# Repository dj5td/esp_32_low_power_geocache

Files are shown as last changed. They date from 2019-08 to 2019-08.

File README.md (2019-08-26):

# ESP 32 low power geocache
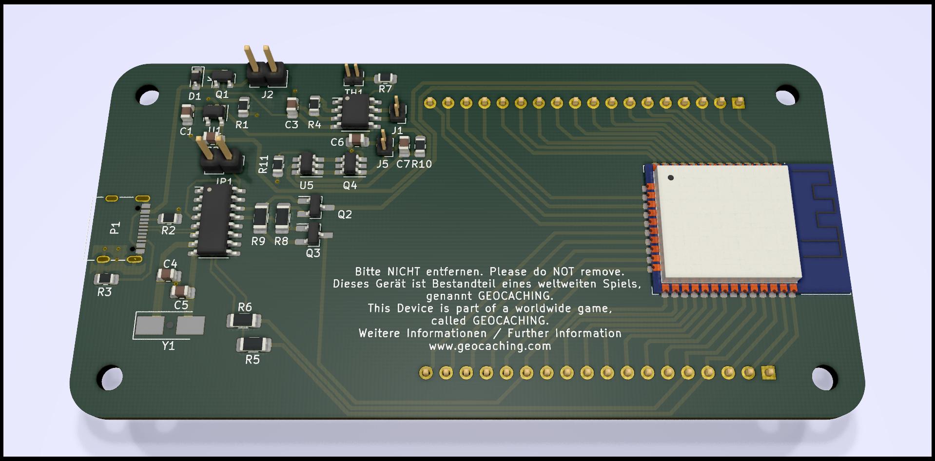
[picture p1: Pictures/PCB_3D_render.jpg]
Smiley face


## Idea and Goals

### Idea

### Goals

## Schematic

## Parts
You can find a bill of materials (BOM) file for LCSC in the repository. Not included are pinheaders, solar panel and the lithium-ion battery.
## Software
Software will be developed once I received and built the first prototype. Hang in there.
## License


This project is licensed under the Creative Commons Attribution-NonCommercial-ShareAlike 4.0 International licence. See the [LICENSE.md](LICENSE.md) file for details.
## Acknowledgments
Special thanks go out to my amateur radio friends who helped me a lot during design of the schematic and PCB:
* Mathias Weyland
* Oliver
* Rune Broberg

You guys show us that amateur radio still is about experimenting with hardware and software, and that it is even more amazing to do so nowadays than ever before. This international community is amazing and I encourage everyone interested in tinkering, creating and engineering to join us.

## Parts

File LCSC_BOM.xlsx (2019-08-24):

LCSC Part Number | Manufacture Part Number | Manufacturer | Package | Description | RoHS | Order Qty. | Min\Mult Order Qty. | Unit Price | Order Price | Product Link
C95209 | ESP32-WROOM-32 | Espressif Systems | Module | WIFI Modules Module RoHS | yes | 3 | 1\1 | 3.197 | 9.591 | https://lcsc.com/product-detail/WIFI-Modules_ESP-WROOM-32_C95209.html
C181158 | S8050 | Guangdong Hottech | SOT-23(SOT-23-3) | Transistors (NPN/PNP) NPN 500mA 25V SOT-23(SOT-23-3) RoHS | yes | 50 | 50\50 | 0.0082 | 0.41 | https://lcsc.com/product-detail/Transistors-NPN-PNP_S8050_C181158.html
C1491 | 1206W4J0123T5E | Uniroyal Elec | 1206 | Chip Resistor - Surface Mount 12KOhms ±5% 1/4W 1206 RoHS | yes | 100 | 100\100 | 0.0018 | 0.18 | https://lcsc.com/product-detail/Chip-Resistor-Surface-Mount_Uniroyal-Elec-1206W4J0123T5E_C1491.html
C118071 | RS-06K471JT | Guangdong Fenghua Advanced Tech | 1206 | Chip Resistor - Surface Mount 470Ohms ±5% 1/4W 1206 RoHS | yes | 100 | 100\100 | 0.0018 | 0.18 | https://lcsc.com/product-detail/Chip-Resistor-Surface-Mount_470R-471-5_C118071.html
C115337 | RS-05K512JT | Guangdong Fenghua Advanced Tech | 0805 | Chip Resistor - Surface Mount 5.1KOhms ±5% 1/8W 0805 RoHS | yes | 100 | 100\100 | 0.0011 | 0.11 | https://lcsc.com/product-detail/Chip-Resistor-Surface-Mount_5-1KR-512-5_C115337.html
C102017 | CR0805J80472G | LIZ Elec | 0805 | Chip Resistor - Surface Mount 4.7KOhms ±5% 1/8W 0805 RoHS | yes | 100 | 100\100 | 0.0011 | 0.11 | https://lcsc.com/product-detail/Chip-Resistor-Surface-Mount_4-7KR-472-5_C102017.html
C1365 | 0805W8J0362T5E | Uniroyal Elec | 0805 | Chip Resistor - Surface Mount 3.6KOhms ±5% 1/8W 0805 RoHS | yes | 100 | 100\100 | 0.0011 | 0.11 | https://lcsc.com/product-detail/Chip-Resistor-Surface-Mount_Uniroyal-Elec-0805W8J0362T5E_C1365.html
C115302 | RS-05K102JT | Guangdong Fenghua Advanced Tech | 0805 | Chip Resistor - Surface Mount 1KOhms ±5% 1/8W 0805 RoHS | yes | 100 | 100\100 | 0.001 | 0.1 | https://lcsc.com/product-detail/Chip-Resistor-Surface-Mount_1KR-102-5_C115302.html
C24658 | 0805CG220J500NT | Guangdong Fenghua Advanced Tech | 0805 | Multilayer Ceramic Capacitors MLCC - SMD/SMT 22pF 50V 0805 RoHS | yes | 50 | 50\50 | 0.0051 | 0.255 | https://lcsc.com/product-detail/Multilayer-Ceramic-Capacitors-MLCC-SMD-SMT_22pF-220-5-50V_C24658.html
C307523 | CL21A106KPFNNNG | Samsung Electro-Mechanics | 0805 | Multilayer Ceramic Capacitors MLCC - SMD/SMT 10uF 10V 0805 RoHS | yes | 50 | 50\50 | 0.0089 | 0.445 | https://lcsc.com/product-detail/Others_Samsung-Electro-Mechanics_CL21A106KPFNNNG_Samsung-Electro-Mechanics-CL21A106KPFNNNG_C307523.html
C96454 | CL21A475KPFNNNE | Samsung Electro-Mechanics | 0805 | Multilayer Ceramic Capacitors MLCC - SMD/SMT 4.7uF 10V 0805 RoHS | yes | 50 | 50\50 | 0.013 | 0.65 | https://lcsc.com/product-detail/Others_Samsung-Electro-Mechanics_CL21A475KPFNNNE_Samsung-Electro-Mechanics-CL21A475KPFNNNE_C96454.html
C112573 | X503212MSB2GI | Yangxing Tech | SMD-5032_2P | SMD Crystal Resonators 12MHz ±10ppm SMD-5032_2P RoHS | yes | 3 | 1\1 | 0.1727 | 0.5181 | https://lcsc.com/product-detail/SMD-Crystal-Resonators_Yangxing-Tech-X503212MSB2GI_C112573.html
C319148 | U262-161N-4BVC11 | XKB Enterprise | SMT | USB Connectors SMT RoHS | yes | 3 | 1\1 | 0.3136 | 0.9408 | https://lcsc.com/product-detail/USB-Connectors_XKB-Enterprise-U262-16XN-4BVC11_C319148.html
C123378 | MF52A103J3950 (A1) | Nanjing Shiheng Elec | Through Hole,P=1.7mm | NTC Thermistors 1/20W 10KOhms ±5% 3950K Through Hole,P=1.7mm RoHS | yes | 20 | 20\20 | 0.0263 | 0.526 | https://lcsc.com/product-detail/NTC-Thermistors_10K-5_C123378.html
C123899 | B5817WS | Shandong Jingdao Microelectronics | SOD-323 | Schottky Barrier Diodes (SBD) SOD-323 RoHS | yes | 20 | 20\20 | 0.0163 | 0.326 | https://lcsc.com/product-detail/Schottky-Barrier-Diodes-SBD_Shandong-Jingdao-Microelectronics-B5817WS_C123899.html
C77937 | LP2301LT1G | Leshan Radio | SOT-23(SOT-23-3) | MOSFET P Trench 20V 2.3A 900mV @ 250uA 100 mΩ @ 2.8A,4.5V SOT-23(SOT-23-3) RoHS | yes | 10 | 10\10 | 0.033 | 0.33 | https://lcsc.com/product-detail/MOSFET_Leshan-Radio-LP2301LT1G_C77937.html
C14267 | CH340G | Jiangsu Qin Heng | SOP-16_150mil | USB 2Mbps 3.3V, 5V SOP-16_150mil RoHS | yes | 3 | 1\1 | 0.4061 | 1.2183 | https://lcsc.com/product-detail/USB_CH340G_C14267.html
C86534 | XC6220B331MR-G | Torex Semicon | SOT-25 | Low Dropout Regulators(LDO) Positive Fixed 655mV @ 1A 6V 3.3V 1A SOT-25 RoHS | yes | 3 | 1\1 | 0.2515 | 0.7545 | https://lcsc.com/product-detail/Low-Dropout-Regulators-LDO_XC6220B331MR-G_C86534.html
C28078 | CN3063 | ShangHai Consonance Elec | SOIC-8_EP_150mil | PMIC - Battery Management SOIC-8_EP_150mil RoHS | yes | 3 | 1\1 | 0.5455 | 1.6365 | https://lcsc.com/product-detail/PMIC-AC-DC-Converters_ShangHai-Consonance-Elec-CN3063_C28078.html

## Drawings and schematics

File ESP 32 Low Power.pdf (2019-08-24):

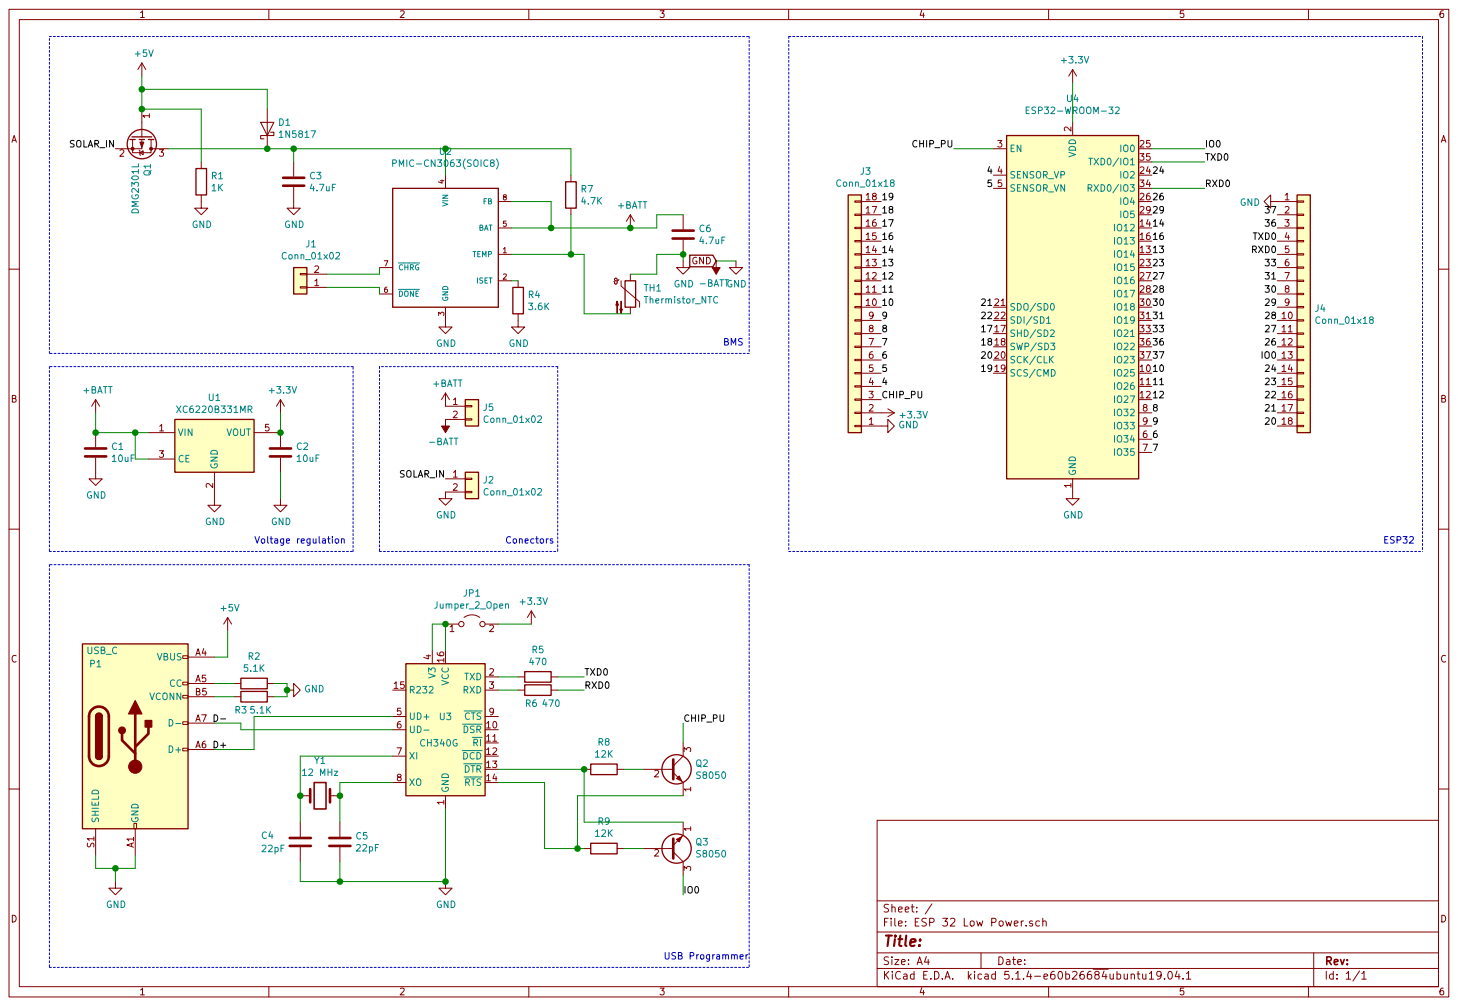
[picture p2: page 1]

4 BAT 5 DONE 6 CHRG 7 FB 8 U2 PMIC-CN3063(SOIC8) D1

2 SCK/CLK 20 SDO/SD0 21 SDI/SD1 22

2 CE 3 VOUT 5 U1 XC6220B331MR GND GND

Id: 1/1 Title: File: ESP 32 Low Power.sch Sheet: / +5V

1 DSR 10 RI 11 DCD 12 DTR 13 RTS 14 R232 15 VCC 16 TXD 2 RXD 3 V3

4 UD+ 5 UD- 6 XI 7 XO 8 CTS 9 U3 CH340G

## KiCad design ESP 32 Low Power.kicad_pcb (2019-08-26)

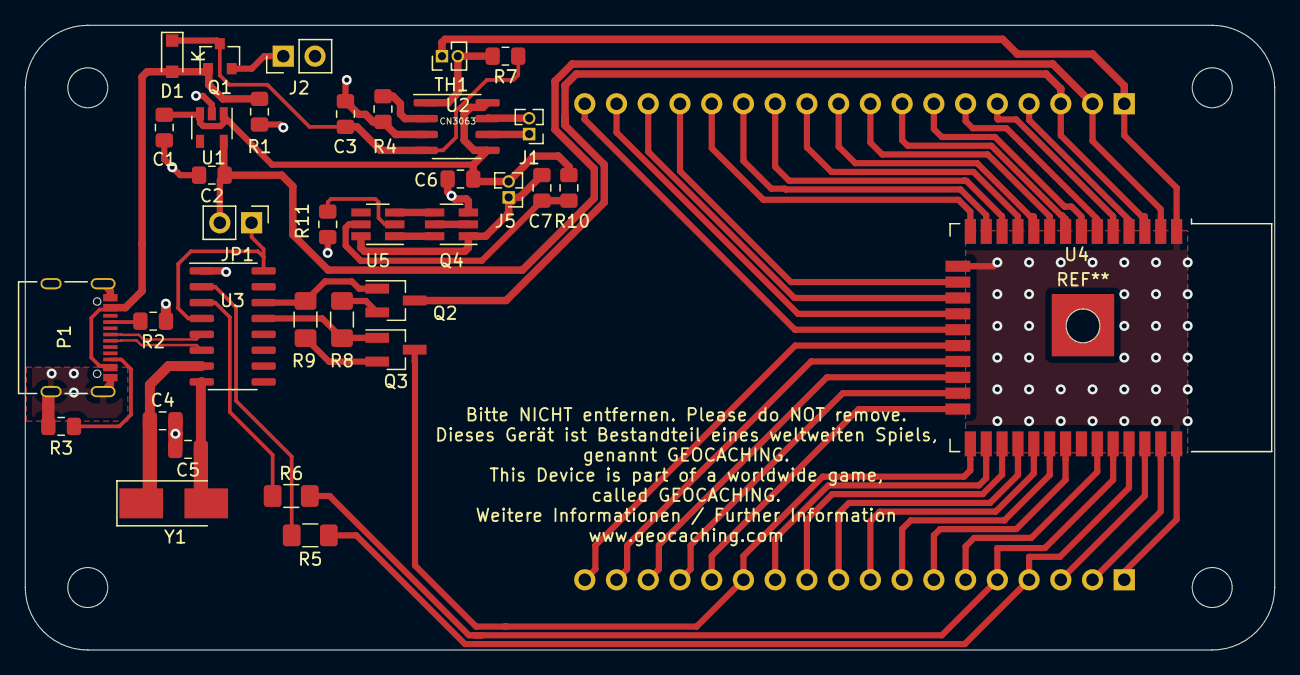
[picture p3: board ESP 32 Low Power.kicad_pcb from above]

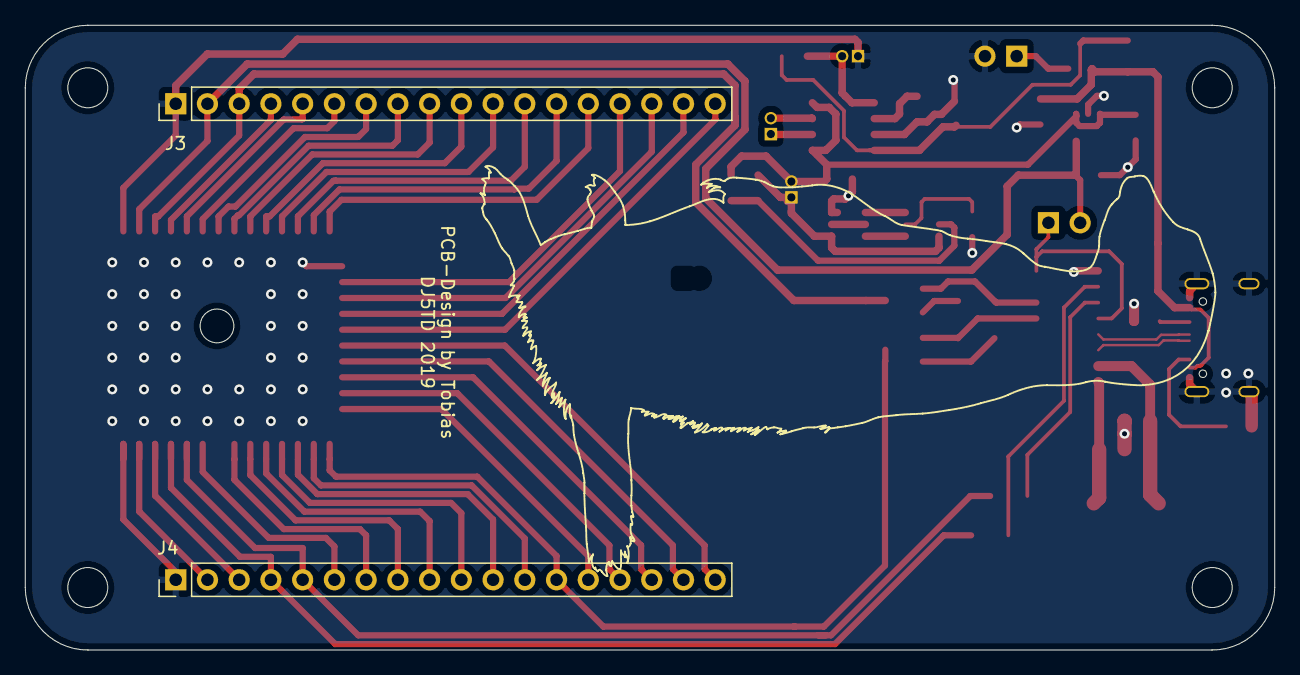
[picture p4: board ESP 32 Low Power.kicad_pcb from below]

Board: 2 copper layers, 100.0 x 50.0 mm, 37 parts (2 on the bottom side), 62 nets.

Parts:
C1, C2: 10uF; C_0805_2012Metric_Pad1.15x1.40mm_HandSolder
C3, C6: 4.7uF; C_0805_2012Metric_Pad1.15x1.40mm_HandSolder
C4, C5: 22pF; C_0805_2012Metric_Pad1.15x1.40mm_HandSolder
C7: 0.1uF; C_0805_2012Metric_Pad1.15x1.40mm_HandSolder
D1: 1N5817; D_SOD-323_HandSoldering
J1: Conn_01x02; PinHeader_1x02_P1.27mm_Vertical
J2: Conn_01x02; PinHeader_1x02_P2.54mm_Vertical
J3, J4: Conn_01x18; PinHeader_1x18_P2.54mm_Vertical
J5: Battery; PinHeader_1x02_P1.27mm_Vertical
JP1: Jumper_2_Open; PinHeader_1x02_P2.54mm_Vertical
P1: USB_C; USB_C_Receptacle_Palconn_UTC16-G
Q1: DMG2301L; SOT-23
Q2, Q3: S8050; SOT-23_Handsoldering
Q4: SE8810A; SOT-23-6_Handsoldering
R1, R11: 1K; R_0805_2012Metric_Pad1.15x1.40mm_HandSolder
R2, R3: 5.1K; R_0805_2012Metric_Pad1.15x1.40mm_HandSolder
R4: 3.6K; R_0805_2012Metric_Pad1.15x1.40mm_HandSolder
R5, R6: 470; R_1206_3216Metric_Pad1.42x1.75mm_HandSolder
R7: 4.7K; R_0805_2012Metric_Pad1.15x1.40mm_HandSolder
R8, R9: 12K; R_1206_3216Metric_Pad1.42x1.75mm_HandSolder
R10: 100R; R_0805_2012Metric_Pad1.15x1.40mm_HandSolder
TH1: Thermistor_NTC; PinHeader_1x02_P1.27mm_Vertical
U1: XC6220B331MR; SOT-23-5
U2: CN3063; SOIC-8_3.9x4.9mm_P1.27mm
U3: CH340G; SOIC-16_3.9x9.9mm_P1.27mm
U4: ESP32-WROOM-32
U5: DW01B; SOT-23-6_Handsoldering
Y1: 12 MHz; Crystal_SMD_5032-2Pin_5.0x3.2mm_HandSoldering

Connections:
+3V3: C2.1, J3.2, JP1.2, U1.5, U4.2
+5V: D1.2, P1.A4, P1.A9, P1.B4, P1.B9, Q1.1, R1.1
+BATT: C1.1, C6.1, J5.2, R10.2, U1.1, U1.3, U2.5, U2.8
/4: J3.4, U4.4
/5: J3.5, U4.5
/6: J3.6, U4.6
/7: J3.7, U4.7
/8: J3.8, U4.8
/9: J3.9, U4.9
/10: J3.10, U4.10
/11: J3.11, U4.11
/12: J3.12, U4.12
/13: J3.13, U4.13
/14: J3.14, U4.14
/16: J3.15, U4.16
/17: J3.16, U4.17
/18: J3.17, U4.18
/19: J3.18, U4.19
/20: J4.18, U4.20
/21: J4.17, U4.21
/22: J4.16, U4.22
/23: J4.15, U4.23
/24: J4.14, U4.24
/26: J4.12, U4.26
/27: J4.11, U4.27
/28: J4.10, U4.28
/29: J4.9, U4.29
/30: J4.8, U4.30
/31: J4.7, U4.31
/33: J4.6, U4.33
/36: J4.3, U4.36
/37: J4.2, U4.37
/CHIP_PU: J3.3, Q2.3, U4.3
/D+: P1.A6, U3.5
/D-: P1.A7, U3.6
/IO0: J4.13, Q3.3, U4.25
/RXD0: J4.5, R6.1, U4.34
/SOLAR_IN: J2.1, Q1.2
/TXD0: J4.4, R5.1, U4.35
GND: C1.2, C2.2, C3.2, C4.2, C5.2, C6.2, J2.2, J3.1, J4.1, P1.A1, P1.A12, P1.B1, P1.B12, P1.S1, Q4.3, R1.2, R2.1, R3.1, R4.2, R11.2, TH1.1, U1.2, U2.3, U3.1, U4.1, U4.15, U4.38
unnamed: C3.1, D1.1, Q1.3, R7.1, U2.4
unnamed: C4.1, U3.7, Y1.1
unnamed: C5.1, U3.8, Y1.2
unnamed: C7.1, R10.1, U5.5
unnamed: C7.2, J5.1, Q4.1, U5.6
unnamed: J1.1, U2.6
unnamed: J1.2, U2.7
unnamed: JP1.1, U3.4, U3.16
unnamed: P1.A5, R2.2
unnamed: P1.B5, R3.2
unnamed: Q2.1, R9.2, U3.14
unnamed: Q2.2, R8.1
unnamed: Q3.1, R8.2, U3.13
unnamed: Q3.2, R9.1
unnamed: Q4.2, Q4.5
unnamed: Q4.4, U5.3
unnamed: Q4.6, U5.1
unnamed: R4.1, U2.2
unnamed: R5.2, U3.2
unnamed: R6.2, U3.3
unnamed: R7.2, TH1.2, U2.1
unnamed: R11.1, U5.2

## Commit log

2019-08-24 First commit.
    [ESP 32 Low Power.kicad_pcb, ESP 32 Low Power.sch, LCSC_BOM.xlsx]
2019-08-26 Added battery low voltage protection
    [ESP 32 Low Power.kicad_pcb, ESP 32 Low Power.sch]
2019-08-26 Some better placement
    [ESP 32 Low Power.kicad_pcb]
